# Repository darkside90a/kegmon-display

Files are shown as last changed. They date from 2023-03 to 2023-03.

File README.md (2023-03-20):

# kegmon-display
A variant of mp-se's Kegmon display case

You find a complete description of his great Kegmon project here:

https://github.com/mp-se/kegmon

I used a Kemo G081N (120x70x35mm). 
If you are situated in Sweden/Norway, you can get it from Kjell&Co (#89026):
P1010688

Lid off. All modules are on the top side:
P1010693

A hole in the lid is filled with a CNC machined piece of 4mm acrylic as a window (km-display.stl):
P1010697
kegmon-display

Two spacers (km-spacer.stl) lifts the PCB up from the bottom of the case so that the displays are as close to the acrylic window as possible. Both spacers are printed the same way. I just flipped one of them during assembly.
The frame (km-frame1.stl) keeps the displays as horizontal as possible.
P1010694
km-spacer
km-frame

All modules are mounted on sockets - "plug-in", easy if I need to replace any of them. Displays are mounted on double height sockets. They have some distance, allowing 1.3" display replacement. RJ45's are placed upside-down to keep the assembly as low as possible. They have extra mechanical support by help of cable strips.
P1010696

Bottom. Took me only 2-3hrs to do all wiring on the 60x80mm experiment PCB:

P1010695

Brackets for mounting the frame were made by "killing" two of these car cable interconnectors and soldered on to the PCB: 
P1010692

Before soldering, I made a design in KiCad with 3D models to see how it would look like. Also did a rough layout to have something to check against:


Regrets:

If I was asked to make this again, I would have moved the ESP one more step (2.5mm) away from the edge of the PCB 
( = A much smaller cutout in the case).

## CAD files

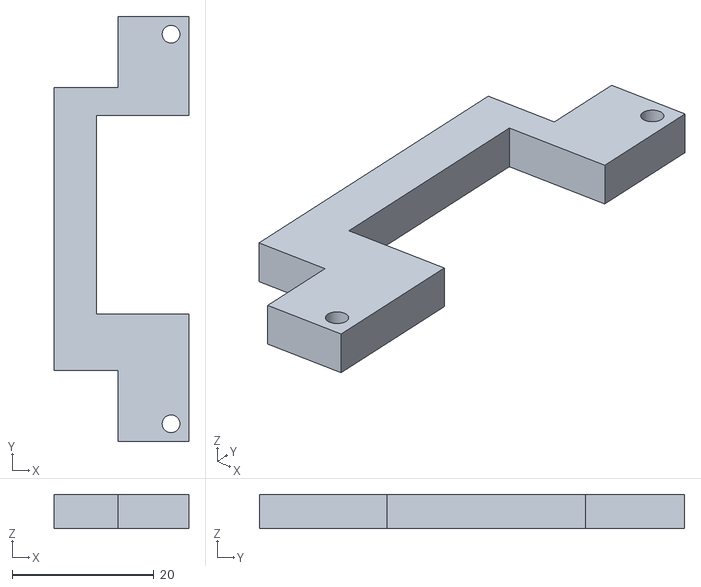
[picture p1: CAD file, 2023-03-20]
km-spacer.stl
19.0 x 60.0 x 4.80

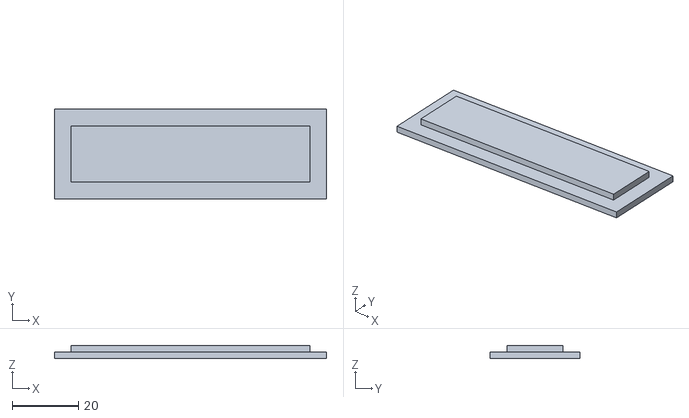
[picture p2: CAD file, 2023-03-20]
km-display.stl
82.0 x 27.0 x 4.00

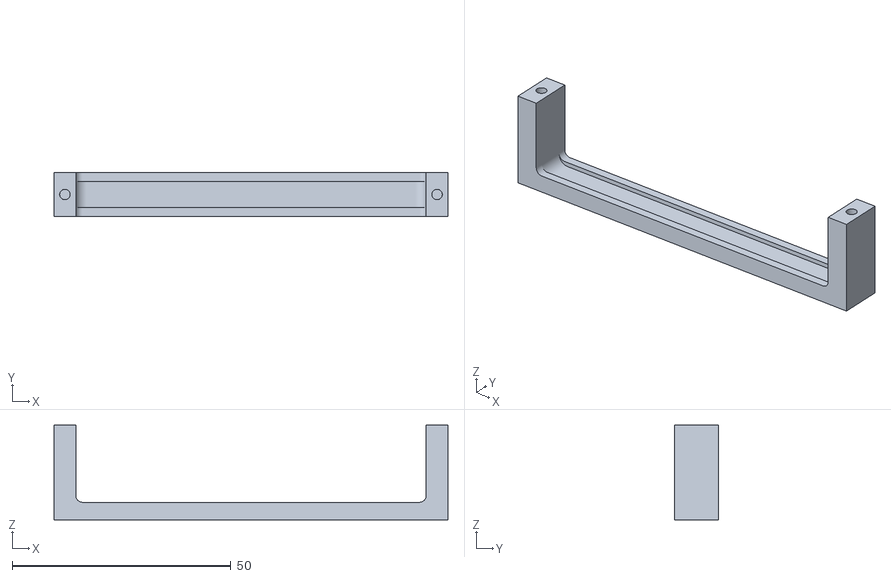
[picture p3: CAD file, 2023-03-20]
km-frame1.stl
90.0 x 10.0 x 21.6
